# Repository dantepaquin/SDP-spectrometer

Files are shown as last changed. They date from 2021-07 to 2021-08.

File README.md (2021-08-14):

# SDP-Spectrometer

This is the joint repository for the hardware and software for the UCSC EE SDP 2021 Spectrometer. 
The directory *kicad-libraries* contains all of the design files for the hardware, including the schematics, kicad projects, footprint & symbol libraries, and gerbers.
The directory *microcontroller-libraries* contains all of the software used by our spectrometer.

## Kicad Libraries
In our design, we used [KiCad v5.1.0](https://www.kicad.org/blog/2019/03/KiCad-5.1.0-Release/) to create libraries for footprints, symbols, schematics, and pcbs. Currently, the initial designs are in their first revision, and we have fabricated prototypes to be tested.

While our design uses five separate boards connected with wires, all designs are located within a single KiCad project, "main.pro."

### Overview of directories:
#### Adafruit-PowerBoost-1000C-master/
Our design uses an existing power delivery board, and this folder contains the physical design documents that we referenced and used in our own.

#### Backup/
An almost-empty folder used for managing local backups and versioining. Can be removed.

#### RN4678dev/
This contains a kicad project and its design files for a development board, opening the SMD footprint to machine headers. These are not necessary for the final design.

#### Renders/
This contains PDF views of the current PCBs, shown with a small selection of layers.

#### SC70-Dev/
This is a development board used for the SC70 footprint, allowing breadboard verification of our systems. This contains a kicad project with the scematic and PCB files.

#### Separate/
This directory contains subdirectories for each of the five PCBs of our design, which allowed us to manufacture individual boards rather than the full set. This also includes the gerbers used to manufacture the initial run of boards. 

#### Wiring Diagram/
This was a development project to identify and plan the necessary connections between the components of our design. It exists for reference, and has no physical form.

#### spectrometer_core.pretty/
This is the footprint library directory, implementing the physical dimensions and connections of each device used in our design.

#### fp-lib-table
This file tells KiCad how to associate the symbols in our schematic with the footprints in spectrometer_core.pretty.

#### main-cache.lib
This file keeps track of all of the symbols used in the schematic.

#### main.kicad_pcb
This is the main PCB file, which is used to design and lay out the footprints into their physical form.

#### main.pro
**This is the main project file of the spectrometer.** Opening this with kicad will give you access to design and change the footprints, symbols, schematics, and PCBs of the design.

#### main.sch
This is the main schematic file, used to establish connections between the components of the design.

#### spectrometer_core.bck
This is a local backup of the spectrometer_core.dcm file, and can be removed.

#### spectrometer_core.dcm
This keeps track of any documentation we added to the symbol library.

#### spectrometer_core.lib
This is our main symbol library, used to represent the components as used on our schematic.

#### sym-lib-table
This keeps track of the symbol libraries used in the main project.

## Microcontroller Libraries

Our project uses a [TeensyLC](https://www.pjrc.com/teensy/teensyLC.html) running [Arduino](https://www.arduino.cc/en/software), and was developed in the Arduino IDE. This directory contains the code we were able to complete, and verious sketches of test programs.

### Overview of directories:

#### Bluetooth/
This directory contains the currnent state of the bluetooth library implementation. The files include CircularBuffer.c/h, used for UART communication; RN4678.cpp/h, the main library file for the RN4678 bluetooth module; and RN4678_Command.h, a file containing all of the available bluetooth commands.

#### Examples/
This directory includes arduino sketches used to verify both the hardware and minor software usage in our design. These will allow basic back-and-forth, following PC -> USB -> Teesny -> UART -> RN4678 -> Bluetooth -> Phone

#### TeesnyMain/
This is the main directory of code running on the TeensyLC, TeensyMain.ino, and includes state machines and libraries used in our design.  

#### Adafruit_SSD1306.cpp/h
This is an open library by Adafruit designed for our OLED screen, based on the SSD1306 driver IC.

#### FiniteStateMachine.cpp/h
This is an old backup of the driving state machine of our microcontroller. The updated version is in TeensyMain/

#### LED.cpp/h
These files are basic LED drivers for arduino, and can be ignored.

#### RN4678_Command.h
This is a backup of the same file located in Bluetooth/. Both files include usage documentation inside

#### TeensyMain.ino
This is an old backup of the main arduino sketch within TeensyMain/, and can be ignored.

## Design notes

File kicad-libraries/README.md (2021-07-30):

# Repository for KiCad Libraries and design

Individual design files (footprints & symbols) will go into part-specific subfolders in the "Separate" folder

KiCad organization basics:  
.LIB files store SCHEMATIC SYMBOLS  
.PRETTY folders store FOOTPRINT MODELS  
The two should be associated in their current form. 

Further work includes building basic building-block circuits so that integration is easier later on.

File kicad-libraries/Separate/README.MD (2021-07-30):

# Individual EDA files

This folder contains all of the individual projects for each of the boards.

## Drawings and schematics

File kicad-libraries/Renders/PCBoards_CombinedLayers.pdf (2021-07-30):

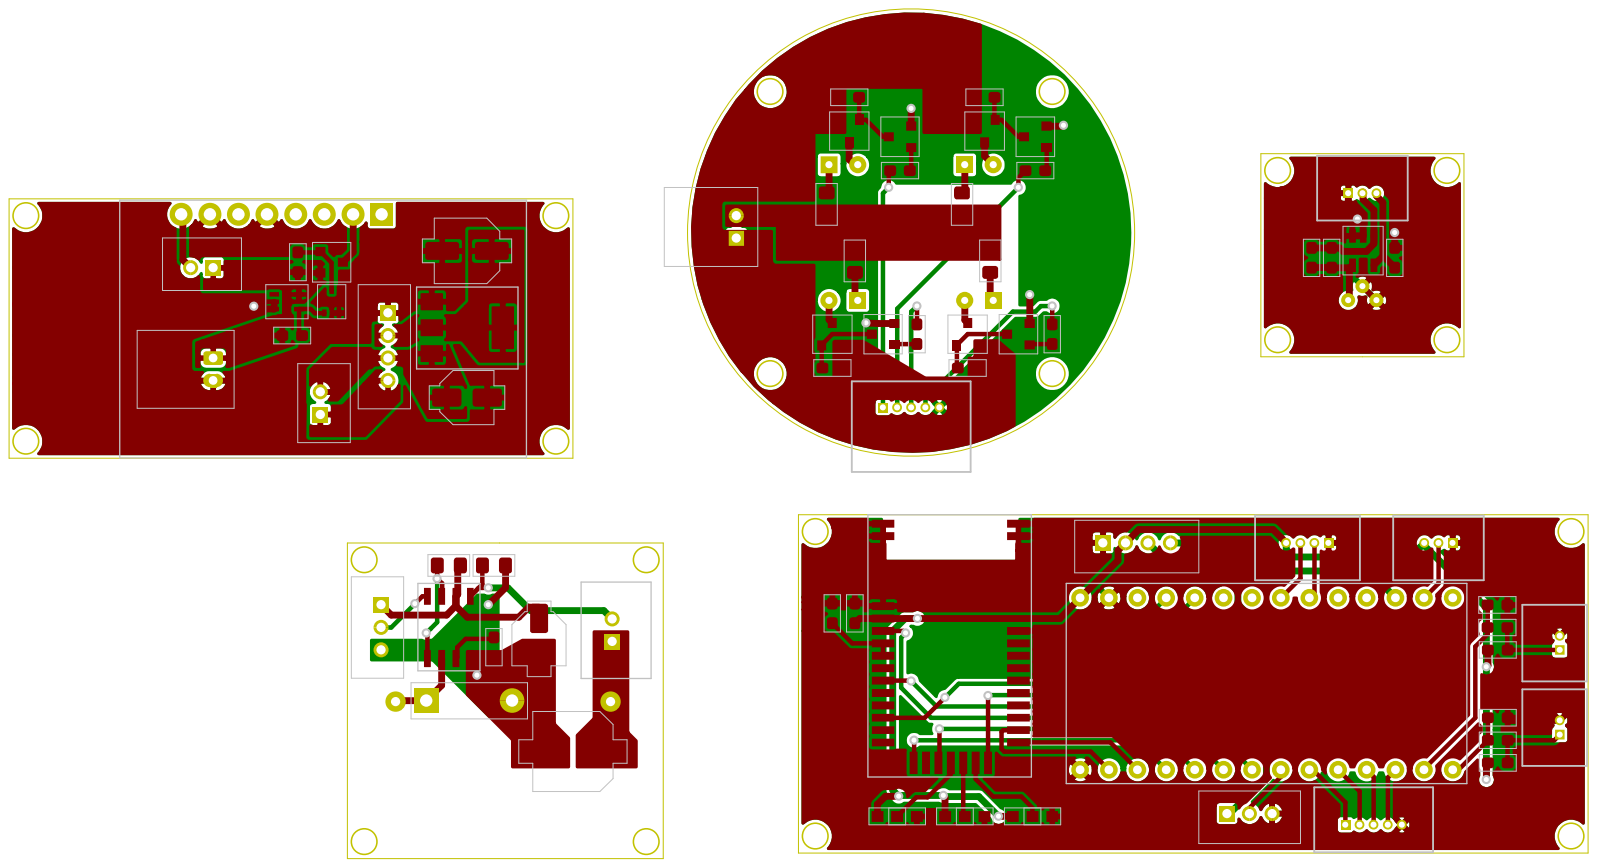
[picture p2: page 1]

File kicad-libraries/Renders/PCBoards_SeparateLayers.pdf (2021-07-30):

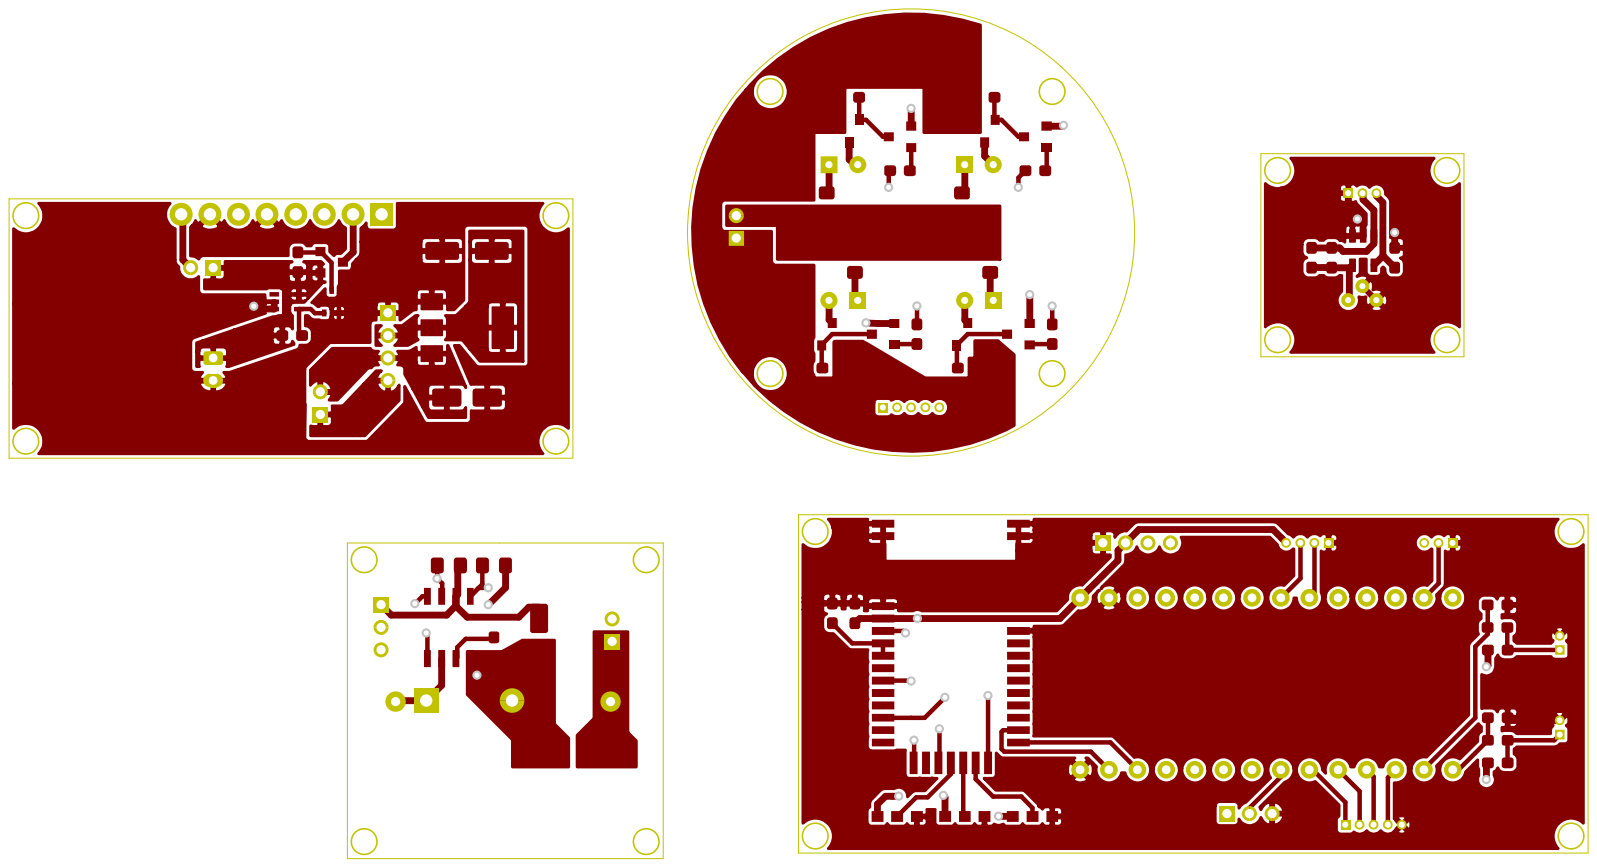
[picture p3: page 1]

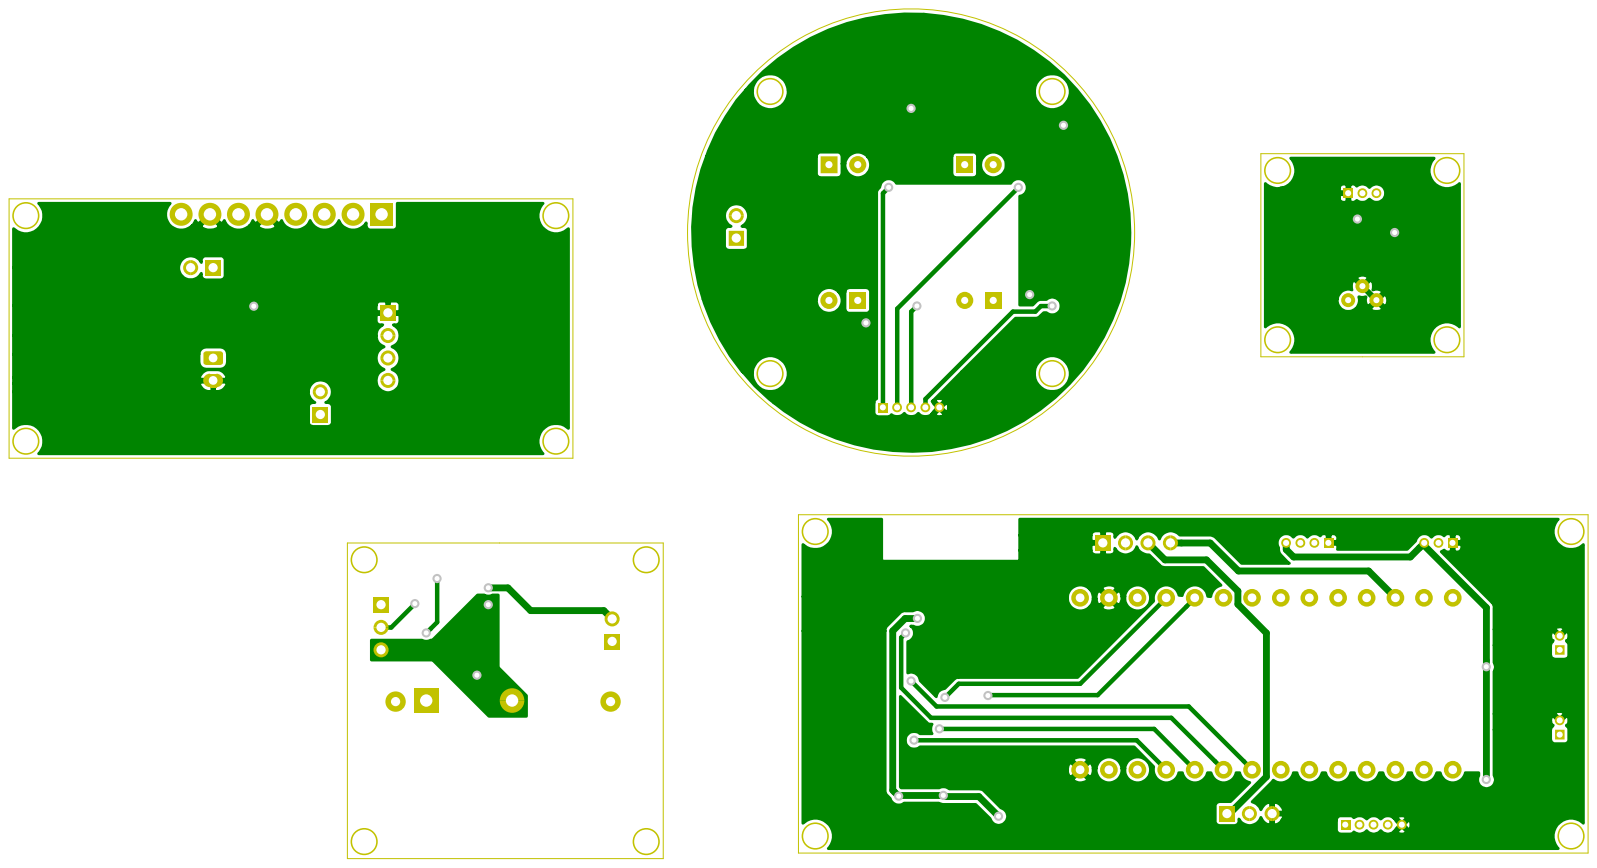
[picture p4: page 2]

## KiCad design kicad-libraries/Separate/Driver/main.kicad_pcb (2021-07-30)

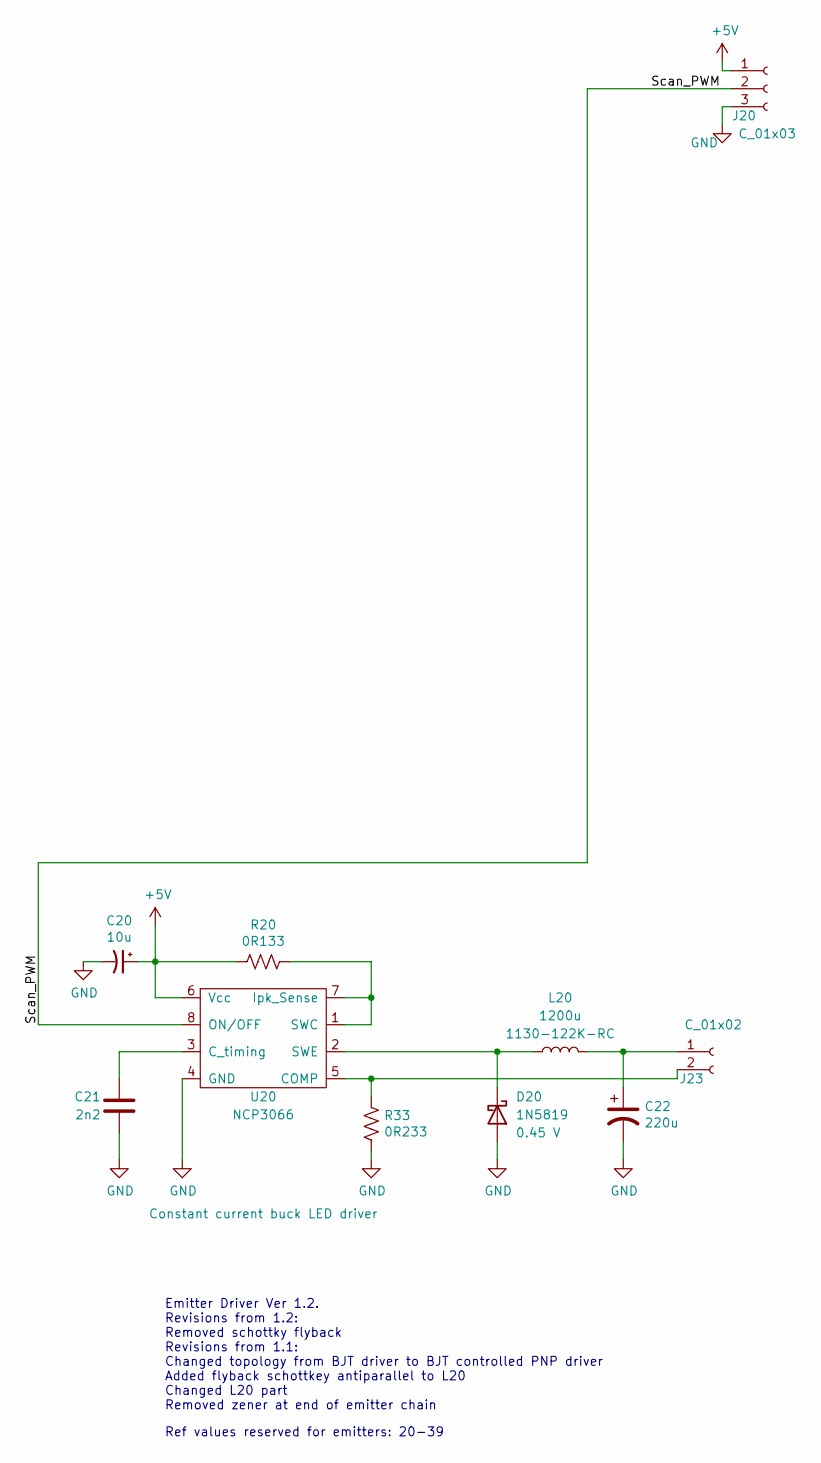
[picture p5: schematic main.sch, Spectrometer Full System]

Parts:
C20: 10u; CP_Elec_4x3
C21: 2n2; C_0603_1608Metric_Pad1.05x0.95mm_HandSolder
C22: 220u; CP_Elec_6.3x5.9
D20: 1N5819; D_DO-41_SOD81_P7.62mm_Horizontal
J20: C_01x03; 1x03_Vert_P2.00_Molex_Micro-Latch
J23: C_01x02; 1x02_Vert_P2.00_Molex_Micro-Latch
L20: 1200u; 1130-122K-RC
R20: 0R133; R_0805_2012Metric_Pad1.15x1.40mm_HandSolder
R33: 0R233; R_0805_2012Metric_Pad1.15x1.40mm_HandSolder
U20: NCP3066; SOIC-8

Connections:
+5V: C20.1, J20.1, R20.1, U20.6 (Vcc)
/Scan_PWM: J20.2, U20.8 (ON/OFF)
GND: C20.2, C21.2, C22.2, D20.2 (A), J20.3, R33.2, U20.4 (GND)
unnamed: C21.1, U20.3 (C_timing)
unnamed: C22.1, J23.1, L20.2
unnamed: D20.1 (K), L20.1, U20.2 (SWE)
unnamed: J23.2, R33.1, U20.5 (COMP)
unnamed: R20.2, U20.1 (SWC), U20.7 (Ipk_Sense)

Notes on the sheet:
Emitter Driver Ver 1.2. Revisions from 1.2: Removed schottky flyback Revisions from 1.1: Changed topology from BJT driver to BJT controlled PNP driver Added flyback schottkey antiparallel to L20 Changed L20 part Removed zener at end of emitter chain
Ref values reserved for emitters: 20-39

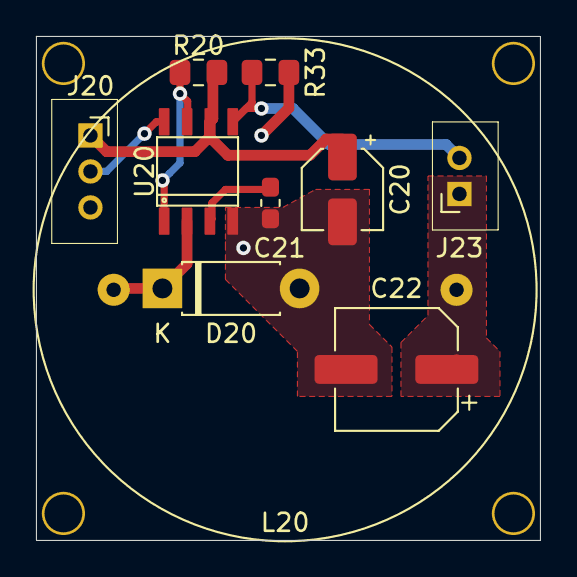
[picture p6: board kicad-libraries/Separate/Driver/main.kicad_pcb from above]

Board: 2 copper layers, 28.0 x 28.0 mm, 10 parts (0 on the bottom side), 8 nets.

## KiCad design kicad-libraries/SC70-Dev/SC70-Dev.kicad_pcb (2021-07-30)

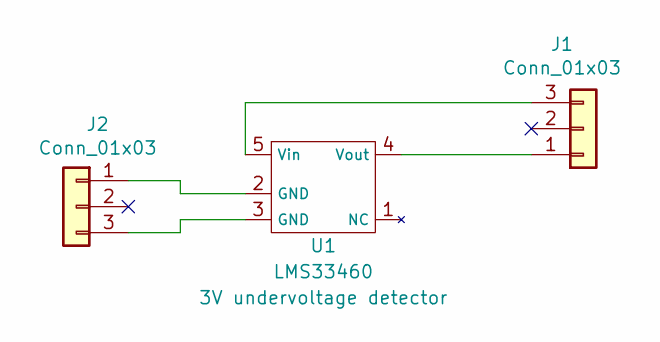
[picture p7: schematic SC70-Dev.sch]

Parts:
J1, J2: Conn_01x03; PinHeader_1x03_P2.54mm_Vertical
U1: LMS33460; SC70

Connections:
unnamed: J1.1, U1.4 (Vout)
unnamed: J1.3, U1.5 (Vin)
unnamed: J2.1, U1.2 (GND)
unnamed: J2.3, U1.3 (GND)

Board: 2 copper layers, 3 parts (0 on the bottom side), 4 nets, no tracks yet.

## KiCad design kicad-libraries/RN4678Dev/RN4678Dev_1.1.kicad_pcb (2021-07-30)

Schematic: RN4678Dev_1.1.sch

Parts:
C1, C2: C; C_0603_1608Metric
D1: LED; LED_0603_1608Metric
J1, J2: Conn_01x11_Male; PinHeader_1x11_P2.54mm_Vertical
JP1, JP2, JP3: J3; PinHeader_1x03_P2.54mm_Vertical
M1: RN4678
R1: R; R_0603_1608Metric

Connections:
+BATT: C1.1, J1.1, JP1.3, JP2.3, JP3.3, M1.4 (BAT_IN)
/04: J1.5, M1.11 (P0_4)
/05: J1.9, M1.16 (P0_5)
/12: J1.7, M1.13 (P1_2)
/13: J1.8, M1.14 (P1_3)
/15: J1.6, M1.12 (P1_5)
/31: J2.5, M1.24 (P3_1)
/32: J2.6, M1.25 (P3_2)
/33: J2.7, M1.26 (P3_3)
/34: J2.8, M1.27 (P3_4)
/36: J2.9, M1.28 (P3_6)
/37: J2.10, M1.29 (P3_7)
/CTS: J2.1, M1.15 (P1_7/CTS)
/LDO33: C2.1, M1.6 (LDO33_O), M1.7 (VDD_IO), R1.2
/RST_N: J1.10, M1.21 (RST_N)
/RTS: J2.2, M1.17 (P0_0/RTS)
/RXD: J2.3, M1.22 (RXD)
/SWBTN: J1.3, M1.5 (SW_BTN)
/TXD: J2.4, M1.23 (TXD)
/WAKEUP: J1.4, M1.9 (WAKEUP)
GND: C1.2, C2.2, J1.2, J1.11, J2.11, JP1.1, JP2.1, JP3.1, M1.1 (GND), M1.2 (GND), M1.3 (GND), M1.31 (GND), M1.32 (GND), M1.33 (GND)
unnamed 21: D1.1 (K), M1.30 (LED); also elsewhere on the board
unnamed 22: R1.1; also elsewhere on the board
unnamed: JP1.2, M1.18 (P2_0)
unnamed: JP2.2, M1.19 (P2_4)
unnamed: JP3.2, M1.20 (EAN)

Board: 2 copper layers, 10 parts (3 on the bottom side), 26 nets, no tracks yet.

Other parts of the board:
>|: LED; LED_0603_1608Metric

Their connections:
unnamed 21: >|.1; also elsewhere on the board
unnamed 22: >|.2; also elsewhere on the board

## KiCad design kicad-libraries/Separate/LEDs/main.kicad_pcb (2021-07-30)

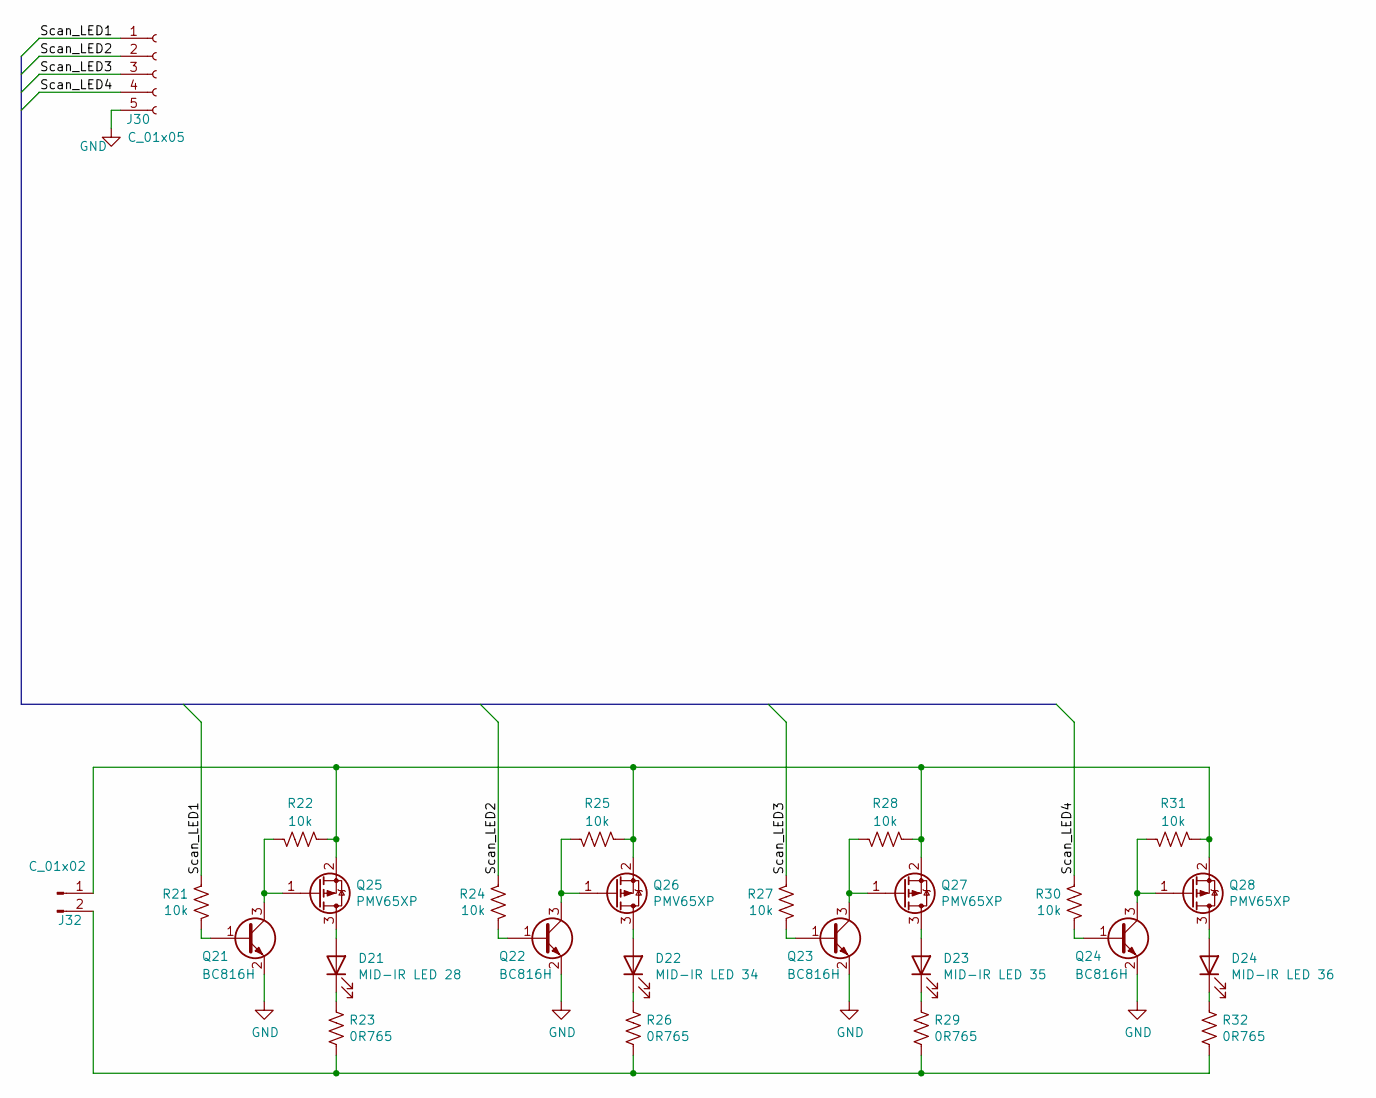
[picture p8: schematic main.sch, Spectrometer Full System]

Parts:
D21: MID-IR LED 28; TO-18R
D22: MID-IR LED 34; TO-18R
D23: MID-IR LED 35; TO-18R
D24: MID-IR LED 36; TO-18R
J30: C_01x05; 530480550
J32: C_01x02; 1x02_Horiz_P2.00_Molex_Micro-Latch
Q21, Q22, Q23, Q24: BC816H; SOT-23
Q25, Q26, Q27, Q28: PMV65XP; SOT-23
R21, R22, R24, R25, R27, R28, R30, R31: 10k; R_0603_1608Metric_Pad1.05x0.95mm_HandSolder
R23, R26, R29, R32: 0R765; R_0805_2012Metric_Pad1.15x1.40mm_HandSolder

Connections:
/Scan_LED1: J30.1, R21.1
/Scan_LED2: J30.2, R24.1
/Scan_LED3: J30.3, R27.1
/Scan_LED4: J30.4, R30.1
GND: J30.5, Q21.2 (E), Q22.2 (E), Q23.2 (E), Q24.2 (E)
unnamed: D21.1 (K), R23.1
unnamed: D21.2 (A), Q25.3 (D)
unnamed: D22.1 (K), R26.1
unnamed: D22.2 (A), Q26.3 (D)
unnamed: D23.1 (K), R29.1
unnamed: D23.2 (A), Q27.3 (D)
unnamed: D24.1 (K), R32.1
unnamed: D24.2 (A), Q28.3 (D)
unnamed: J32.1, Q25.2 (S), Q26.2 (S), Q27.2 (S), Q28.2 (S), R22.1, R25.1, R28.1, R31.1
unnamed: J32.2, R23.2, R26.2, R29.2, R32.2
unnamed: Q21.1 (B), R21.2
unnamed: Q21.3 (C), Q25.1 (G), R22.2
unnamed: Q22.1 (B), R24.2
unnamed: Q22.3 (C), Q26.1 (G), R25.2
unnamed: Q23.1 (B), R27.2
unnamed: Q23.3 (C), Q27.1 (G), R28.2
unnamed: Q24.1 (B), R30.2
unnamed: Q24.3 (C), Q28.1 (G), R31.2

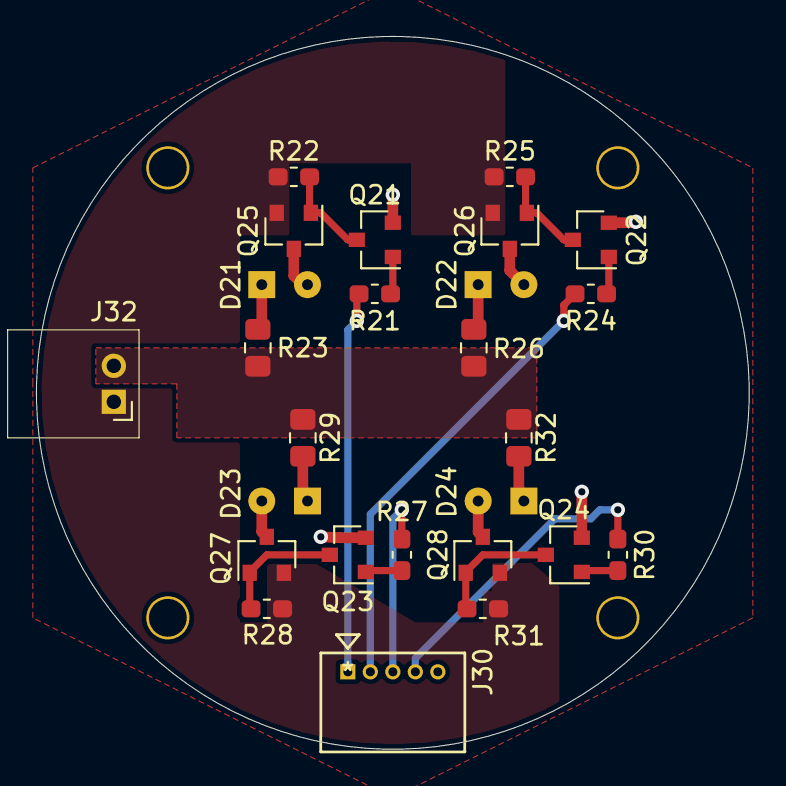
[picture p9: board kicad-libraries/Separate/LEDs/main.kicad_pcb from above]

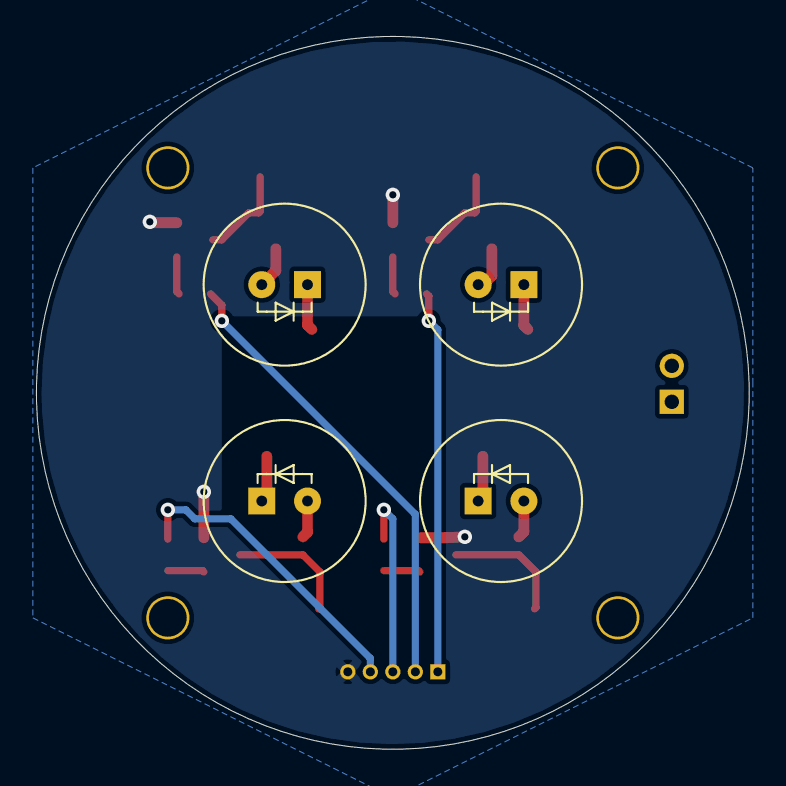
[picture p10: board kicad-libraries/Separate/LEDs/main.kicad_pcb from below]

Board: 2 copper layers, 39.6 x 39.6 mm, 26 parts (4 on the bottom side), 23 nets.

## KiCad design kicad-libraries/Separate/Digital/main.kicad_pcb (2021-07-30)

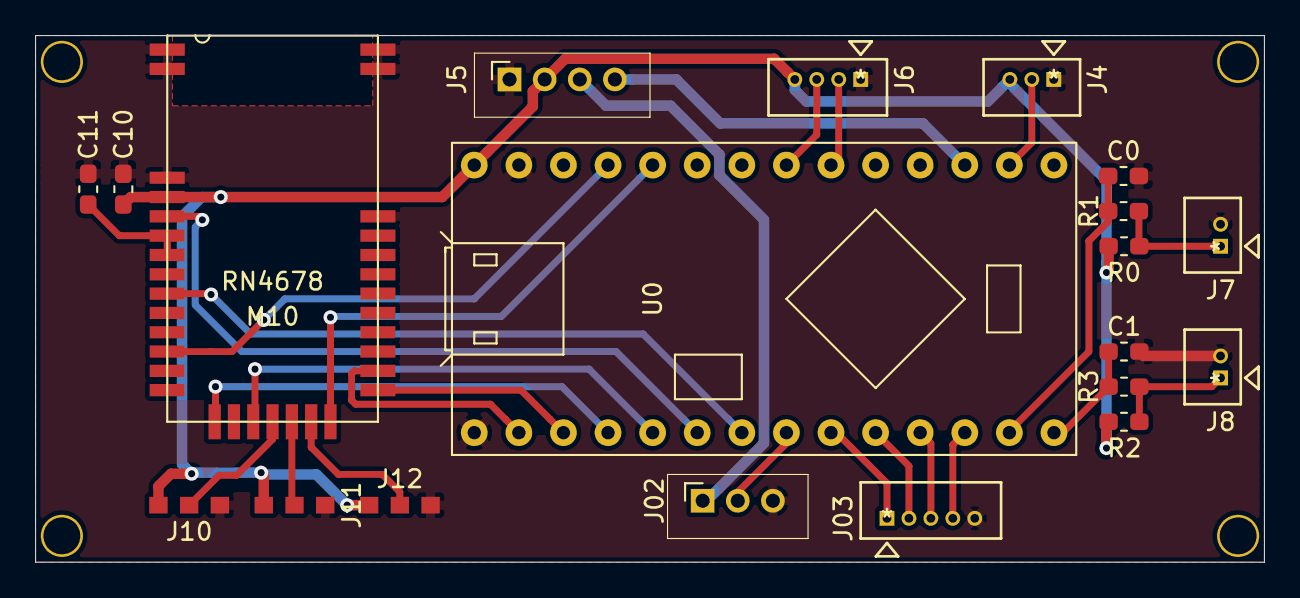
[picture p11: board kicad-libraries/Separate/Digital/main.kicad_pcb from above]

Board: 2 copper layers, 70.0 x 30.0 mm, 20 parts (0 on the bottom side), 28 nets.

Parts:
C0, C1: 0.1u; C_0603_1608Metric_Pad1.05x0.95mm_HandSolder
C10: 10u; C_0603_1608Metric_Pad1.05x0.95mm_HandSolder
C11: 1u; C_0603_1608Metric_Pad1.05x0.95mm_HandSolder
J02: C_01x03; 1x03_Vert_P2.00_Molex_Micro-Latch
J03: C_01x05; 530470510
J4: C_01x03; 530470310
J5: C_01x04; 1x04_Vert_P2.00_Molex_Micro-Latch
J6: C_01x04; 530470410
J7, J8: C_01x02; 530470210
J10, J11, J12: Jmp3; Jumper3_0603
M10: RN4678
R0, R2: 100k; R_0603_1608Metric_Pad1.05x0.95mm_HandSolder
R1, R3: 1k; R_0603_1608Metric_Pad1.05x0.95mm_HandSolder
U0: TeensyLC_Inline

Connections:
+3V3: C10.1, J4.3, J5.2, J6.4, J10.1, J11.1, J12.1, M10.4, R0.1, R2.1, U0.VIN
+5V: J02.1, J5.3
+BATT: J5.4, U0.15
/BT_CTS: M10.15, U0.2
/BT_Power: M10.5, U0.4
/BT_RTS: M10.17, U0.3
/BT_Reset: M10.21, U0.22
/BT_Rx: M10.22, U0.1
/BT_Status: M10.12, U0.23
/BT_Tx: M10.23, U0.0
/BT_Wake: M10.9, U0.5
GND: C0.2, C1.2, C10.2, C11.1, J02.3, J03.5, J4.1, J5.1, J6.1, J7.2, J8.2, J10.2, J11.2, J12.2, M10.1, M10.2, M10.3, M10.31, M10.32, M10.33, U0.GND_1, U0.GND_3
unnamed: C0.1, R1.1, U0.11
unnamed: C1.1, R3.1, U0.12
unnamed: C11.2, M10.6, M10.7
unnamed: J02.2, U0.6
unnamed: J03.1, U0.7
unnamed: J03.2, U0.8
unnamed: J03.3, U0.9
unnamed: J03.4, U0.10
unnamed: J4.2, U0.14
unnamed: J6.2, U0.18
unnamed: J6.3, U0.19
unnamed: J7.1, R0.2, R1.2
unnamed: J8.1, R2.2, R3.2
unnamed: J10.3, M10.18
unnamed: J11.3, M10.19
unnamed: J12.3, M10.20

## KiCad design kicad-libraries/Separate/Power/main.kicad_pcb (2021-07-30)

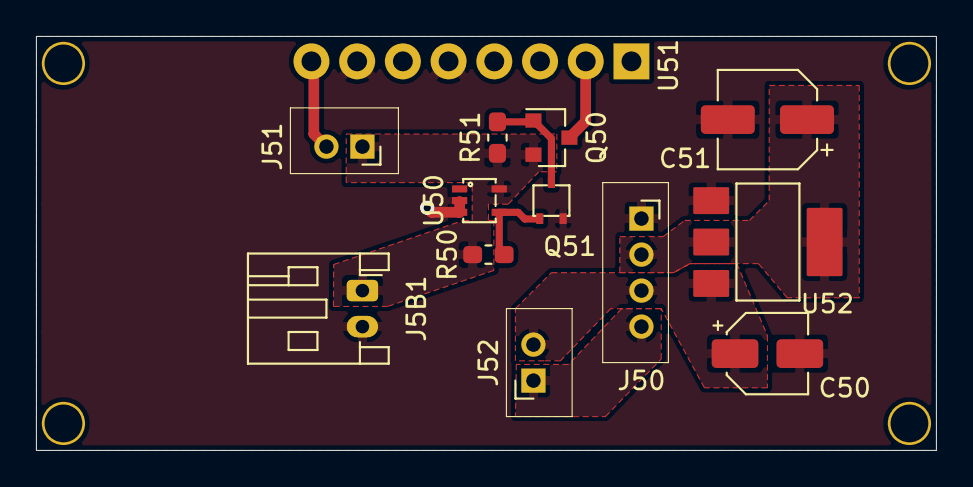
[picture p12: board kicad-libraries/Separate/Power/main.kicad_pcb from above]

Board: 2 copper layers, 50.0 x 23.0 mm, 13 parts (0 on the bottom side), 9 nets.

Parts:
C50: 10u; CP_Elec_4x3
C51: 100u; CP_Elec_5x4.5
J5B1: C_01x02; JST_PH_S2B-PH-K_1x02_P2.00mm_Horizontal
J50: C_01x04; 1x04_Vert_P2.00_Molex_Micro-Latch
J51, J52: C_01x02; 1x02_Vert_P2.00_Molex_Micro-Latch
Q50: SSM3J372R; SOT-23
Q51: SSM3K127TU; UFM-3
R50: 470k; R_0603_1608Metric_Pad1.05x0.95mm_HandSolder
R51: 100k; R_0603_1608Metric_Pad1.05x0.95mm_HandSolder
U50: LMS33460; SC70
U51: PowerBoost1000C; Powerboost1000C
U52: LM1117; SOT-223

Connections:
GND: C50.2, C51.2, J5B1.2, J50.1, Q51.2, U50.2, U50.3, U51.5, U51.7, U52.1
unnamed: C50.1, J50.3, J52.2, U52.3
unnamed: C51.1, J50.2, U52.2
unnamed: J50.4, J52.1
unnamed: J5B1.1, J51.1, Q50.2, R50.1, R51.1, U50.5
unnamed: J51.2, U51.8
unnamed: Q50.1, Q51.3, R51.2
unnamed: Q50.3, U51.2
unnamed: Q51.1, R50.2, U50.4

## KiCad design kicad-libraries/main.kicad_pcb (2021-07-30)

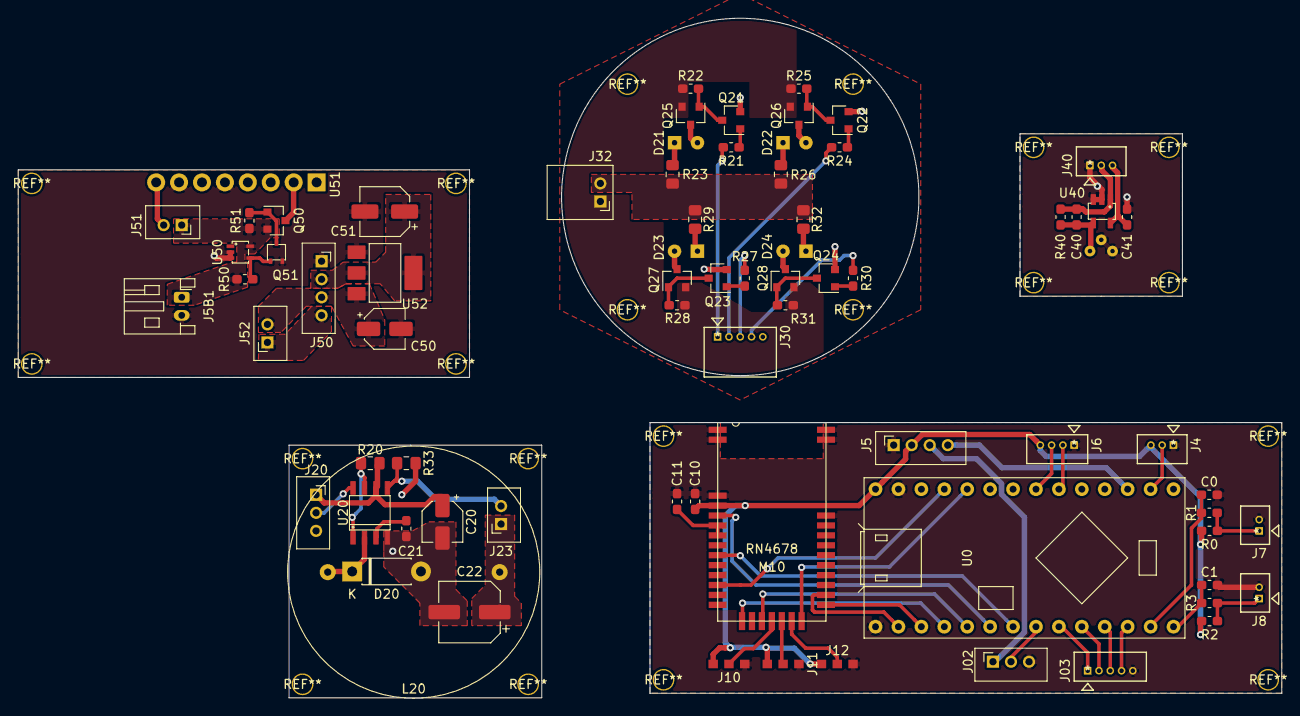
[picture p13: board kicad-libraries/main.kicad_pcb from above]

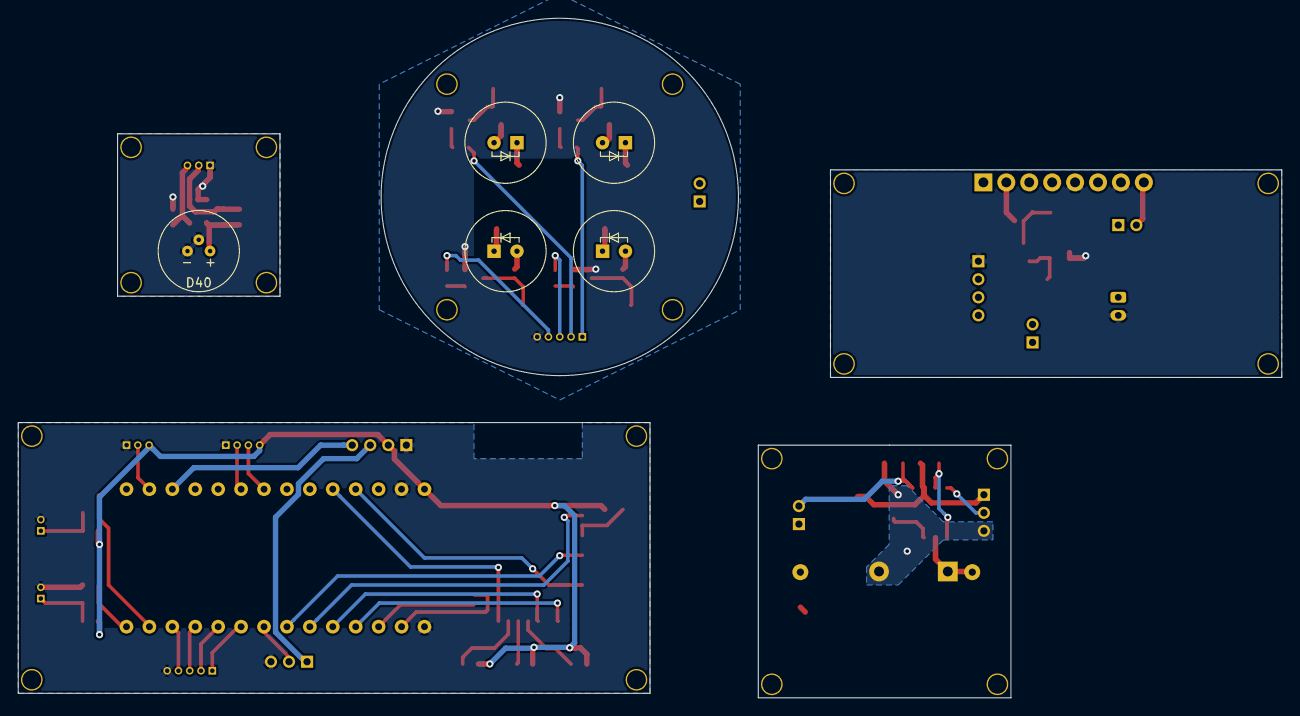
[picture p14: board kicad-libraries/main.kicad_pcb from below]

Board: 2 copper layers, 140.0 x 75.3 mm, 75 parts (5 on the bottom side), 66 nets.

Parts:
C0, C1, C41: 0.1u; C_0603_1608Metric_Pad1.05x0.95mm_HandSolder
C10: 10u; C_0603_1608Metric_Pad1.05x0.95mm_HandSolder
C11: 1u; C_0603_1608Metric_Pad1.05x0.95mm_HandSolder
C20, C50: 10u; CP_Elec_4x3
C21: 2n2; C_0603_1608Metric_Pad1.05x0.95mm_HandSolder
C22: 220u; CP_Elec_6.3x5.9
C40: 27n; C_0603_1608Metric_Pad1.05x0.95mm_HandSolder
C51: 100u; CP_Elec_5x4.5
D20: 1N5819; D_DO-41_SOD81_P7.62mm_Horizontal
D21: MID-IR LED 28; TO-18R
D22: MID-IR LED 34; TO-18R
D23: MID-IR LED 35; TO-18R
D24: MID-IR LED 36; TO-18R
D40: PD41-03; TO-18_WithReflector
J02, J20: C_01x03; 1x03_Vert_P2.00_Molex_Micro-Latch
J03: C_01x05; 530470510
J4, J40: C_01x03; 530470310
J5, J50: C_01x04; 1x04_Vert_P2.00_Molex_Micro-Latch
J5B1: C_01x02; JST_PH_S2B-PH-K_1x02_P2.00mm_Horizontal
J6: C_01x04; 530470410
J7, J8: C_01x02; 530470210
J10, J11, J12: Jmp3; Jumper3_0603
J23, J51, J52: C_01x02; 1x02_Vert_P2.00_Molex_Micro-Latch
J30: C_01x05; 530480550
J32: C_01x02; 1x02_Horiz_P2.00_Molex_Micro-Latch
L20: 1200u; 1130-122K-RC
M10: RN4678
Q21, Q22, Q23, Q24: BC816H; SOT-23
Q25, Q26, Q27, Q28: PMV65XP; SOT-23
Q50: SSM3J372R; SOT-23
Q51: SSM3K127TU; UFM-3
R0, R2, R51: 100k; R_0603_1608Metric_Pad1.05x0.95mm_HandSolder
R1, R3: 1k; R_0603_1608Metric_Pad1.05x0.95mm_HandSolder
R20: 0R133; R_0805_2012Metric_Pad1.15x1.40mm_HandSolder
R21, R22, R24, R25, R27, R28, R30, R31: 10k; R_0603_1608Metric_Pad1.05x0.95mm_HandSolder
R23, R26, R29, R32: 0R765; R_0805_2012Metric_Pad1.15x1.40mm_HandSolder
R33: 0R233; R_0805_2012Metric_Pad1.15x1.40mm_HandSolder
R40: 10k1; R_0603_1608Metric_Pad1.05x0.95mm_HandSolder
R50: 470k; R_0603_1608Metric_Pad1.05x0.95mm_HandSolder
U0: TeensyLC_Inline
U20: NCP3066; SOIC-8
U40: OPA990; SOT-23-5
U50: LMS33460; SC70
U51: PowerBoost1000C; Powerboost1000C
U52: LM1117; SOT-223

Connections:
+3V3: C10.1, C41.1, J4.3, J5.2, J6.4, J10.1, J11.1, J12.1, J40.3, M10.4, R0.1, R2.1, U0.VIN, U40.5
+5V: C20.1, J02.1, J5.3, J20.1, R20.1, U20.6
+BATT: J5.4, U0.15
/BT_CTS: M10.15, U0.2
/BT_Power: M10.5, U0.4
/BT_RTS: M10.17, U0.3
/BT_Reset: M10.21, U0.22
/BT_Rx: M10.22, U0.1
/BT_Status: M10.12, U0.23
/BT_Tx: M10.23, U0.0
/BT_Wake: M10.9, U0.5
/Scan_LED1: J30.1, R21.1
/Scan_LED2: J30.2, R24.1
/Scan_LED3: J30.3, R27.1
/Scan_LED4: J30.4, R30.1
/Scan_PWM: J20.2, U20.8
GND: C0.2, C1.2, C10.2, C11.1, C20.2, C21.2, C22.2, C41.2, C50.2, C51.2, D20.2, D40.1, D40.3, J02.3, J03.5, J4.1, J5.1, J5B1.2, J6.1, J7.2, J8.2, J10.2, J11.2, J12.2, J20.3, J30.5, J40.1, J50.1, M10.1, M10.2, M10.3, M10.31, M10.32, M10.33, Q21.2, Q22.2, Q23.2, Q24.2, Q51.2, R33.2, U0.GND_1, U0.GND_3, U20.4, U40.2, U40.3, U50.2, U50.3, U51.5, U51.7, U52.1
unnamed: C0.1, R1.1, U0.11
unnamed: C1.1, R3.1, U0.12
unnamed: C11.2, M10.6, M10.7
unnamed: C21.1, U20.3
unnamed: C22.1, J23.1, L20.2
unnamed: C40.1, J40.2, R40.2, U40.1
unnamed: C40.2, D40.2, R40.1, U40.4
unnamed: C50.1, J50.3, J52.2, U52.3
unnamed: C51.1, J50.2, U52.2
unnamed: D20.1, L20.1, U20.2
unnamed: D21.1, R23.1
unnamed: D21.2, Q25.3
unnamed: D22.1, R26.1
unnamed: D22.2, Q26.3
unnamed: D23.1, R29.1
unnamed: D23.2, Q27.3
unnamed: D24.1, R32.1
unnamed: D24.2, Q28.3
unnamed: J02.2, U0.6
unnamed: J03.1, U0.7
unnamed: J03.2, U0.8
unnamed: J03.3, U0.9
unnamed: J03.4, U0.10
unnamed: J4.2, U0.14
unnamed: J6.2, U0.18
unnamed: J6.3, U0.19
unnamed: J7.1, R0.2, R1.2
unnamed: J8.1, R2.2, R3.2
unnamed: J10.3, M10.18
unnamed: J11.3, M10.19
unnamed: J12.3, M10.20
unnamed: J23.2, R33.1, U20.5
unnamed: J32.1, Q25.2, Q26.2, Q27.2, Q28.2, R22.1, R25.1, R28.1, R31.1
unnamed: J32.2, R23.2, R26.2, R29.2, R32.2
unnamed: J50.4, J52.1
unnamed: J5B1.1, J51.1, Q50.2, R50.1, R51.1, U50.5
unnamed: J51.2, U51.8
unnamed: Q21.1, R21.2
unnamed: Q21.3, Q25.1, R22.2
unnamed: Q22.1, R24.2
unnamed: Q22.3, Q26.1, R25.2
unnamed: Q23.1, R27.2
unnamed: Q23.3, Q27.1, R28.2
unnamed: Q24.1, R30.2
unnamed: Q24.3, Q28.1, R31.2
unnamed: Q50.1, Q51.3, R51.2
unnamed: Q50.3, U51.2
unnamed: Q51.1, R50.2, U50.4
unnamed: R20.2, U20.1, U20.7

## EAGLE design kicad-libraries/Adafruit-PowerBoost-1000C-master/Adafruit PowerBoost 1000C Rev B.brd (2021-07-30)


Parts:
B1: JST 2-PH; JSTPH2
C1, C7, C8: 10uF; 0805-NO
C2: 2.2uF; 0805-NO
C4: 0.1uF; 0805_10MGAP
C6: 100uF; C1210
CHRG/LBO: ORANGE; CHIPLED_0805_NOOUTLINE
CN1: USBA_FEMALE; USB_HOST-PTH
CN4: MicroUSB; 4UCONN_20329
DONE: GREEN; CHIPLED_0805_NOOUTLINE
FID1, FID2, FID3: FIDUCIAL""; FIDUCIAL_1MM
JP2: HEADER-1X8ROUND; 1X08_ROUND
L1: 6.8uH; INDUCTOR_5X5MM_TDK_VLC5045
LED1: RED; CHIPLED_0805_NOOUTLINE
LED2: BLUE; CHIPLED_0805_NOOUTLINE
R1: 1.87M; _0805MP
R2: 340K; _0805MP
R3: 1.87M; 0805-NO
R4, R13: 200K; 0805-NO
R5, R8, R14, R20: 1K; 0805-NO
R6: 270K; 0805-NO
R7, R17: 100K; 0805-NO
R9: 43K; 0805-NO
R10: 49.9K; 0805-NO
R11: 75K 1%; 0805-NO
R12: 49.9K 1%; 0805-NO
R16: 1.0K; 0805-NO
T1: MMUN2133LT1G; SC59-BEC
THERM: 15K; 0805-NO
U1: TPS61090RSAR; PVQFN-16
U2: MCP73871; QFN20_4MM
U$10, U$11: MOUNTINGHOLE2.5; MOUNTINGHOLE_2.5_PLATED
X1: TERMBLOCK_1X2; TERMBLOCK_1X2-3.5MM

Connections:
5.0V: C2.1, C6.1, CN1.VBUS, JP2.8, R3.2, R5.1, R9.2, R11.2, U1.1 (VOUT), U1.15 (VOUT), U1.16 (VOUT), X1.2
D+: CN1.D+, R11.1, R12.1
D-: CN1.D-, R9.1, R10.1
ENABLE: JP2.4, R13.2, U1.11 (EN)
GND: B1.1 (-), C1.2, C2.2, C4.2, C6.2, C7.2, C8.2, CN1.GND, CN4.BASE@1 (GND), CN4.BASE@2 (GND), CN4.GND, CN4.SPRT@1 (GND), CN4.SPRT@2 (GND), CN4.SPRT@3 (GND), CN4.SPRT@4 (GND), JP2.5, JP2.7, LED1.C, LED2.C, R2.1, R4.1, R7.2, R10.2, R12.2, R16.1, R17.1, THERM.1, U1.5 (PGND), U1.6 (PGND), U1.7 (PGND), U1.10 (SYNC), U1.13 (GND), U1.P$18 (PGND), U1.P$19 (PGND), U1.P$20 (PGND), U1.P$21 (PGND), U1.P$22 (PGND), U1.THERMAL (PGND), U2.P$10 (VSS1), U2.P$11 (VSS2), U2.P$21 (THERMAL), X1.1
LBO: JP2.6, T1.B, U1.12 (LBO)
unnamed: L1.P$2 (2), U1.3 (SW), U1.4 (SW)
unnamed: LED1.A, R20.1
unnamed: R1.1, R2.2, U1.9 (LBI)
unnamed: LED2.A, R5.2
unnamed: R3.1, R4.2, U1.14 (FB)
unnamed: R20.2, T1.C
unnamed: R6.1, R7.1, U2.P$2 (VPCC)
unnamed: DONE.C, R14.2
unnamed: R14.1, U2.P$7 (STAT2)
unnamed: THERM.2, U2.P$5 (THERM)
unnamed: R8.1, U2.P$8 (STAT1/LBO)
unnamed: CHRG/LBO.C, R8.2
unnamed: R17.2, U2.P$12 (PROG3)
unnamed: R16.2, U2.P$13 (PROG1)
VBAT: C1.1, C4.1, JP2.3, L1.P$1 (1), R1.2, R13.1, T1.E, U1.8 (VBAT), U2.P$1 (VOUT1), U2.P$20 (VOUT2)
VBUS: C8.1, CHRG/LBO.A, CN4.VBUS, DONE.A, JP2.1, R6.2, U2.P$3 (SEL), U2.P$4 (PROG2), U2.P$9 (/TE), U2.P$17 (CE), U2.P$18 (VIN1), U2.P$19 (VIN2)
VLIPO: B1.2 (+), C7.1, JP2.2, U2.P$14 (VBAT1), U2.P$15 (VBAT2), U2.P$16 (VBATSENS)

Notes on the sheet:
Both grounds must be connected on the PCB at only one point close to the GND pin.
On/Off Switch
See Pg 15 1st para
6.8uH power w/2A current
R3 = 1.9Mohm for 5.2V R3 = 1.1Mohm for 3.3V
Charge Rate = 1000V/PROG1
1.0K = 1000mA
2.0K = 500mA
No Thermistor:
10K NTC Thermistor:
RT1 = 0, RT2 = 10K
RT1 = TBD, RT2 = TBD



Board: 2 copper layers, 36.1 x 22.9 mm, 47 parts (2 on the bottom side), 23 nets.

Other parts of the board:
U$12: PCBFEAT-REV-040
U$25: SYMBOL_PLUS
U$26: SYMBOL_MINUS
U$28: ADAFRUIT_5MM
U$45: ADAFRUIT_3.5MM

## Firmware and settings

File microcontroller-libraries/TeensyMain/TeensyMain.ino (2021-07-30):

/*
 * TeensyMain
 * 
 * Chris Massiello
 * Last Update: 5/6/2021
 * 
 * Description: This program controls the state of a portable, PLA spectrometer by using a finite
 * state machine. This controls when the spectrometer performs a scan, when the spectrometer tries
 * to connect to a mobile app via bluetooth, and when it goes into power saving mode.
 * 
 */

/*libraries*/
#include <Adafruit_GFX.h>
#include <Adafruit_SSD1306.h>

//
#include "FiniteStateMachine.h"
/*
#define CPU_PRESCALE(n) (CLKPR = 0x80, CLKPR = (n))//defining macro to change cpu clock speed
#define CPU_8MHz        0x01 //values over 8 MHz can be used but would cause the teensy LC to overclock, hence * MHz will be max value that we want to use
#define CPU_4MHz        0x02 //putting these here in case we want to change the cpu clock speed
#define CPU_2MHz        0x03
#define CPU_1MHz        0x04

CPU_PRESCALE(CPU_8MHz);*/


/*creates list of State object that are a part of FSM class
  State STATE = State(method)
  being in the state, STATE, will cause the method passed in State(method) to execute*/
State IDLE_STATE = State(idle);
State POWER_SAVING = State(Power_saving);
State SCANNING = State(scanning);
State BL_SEARCHING = State(BL_search);
State TRANSMITTING = State(data_trans);


/*FSM SPEC = FSM(START), creates finite state machine class that starts in the state named START
  Creates FiniteStateMachine class that will start in the IDLE state*/
FSM SPEC = FSM(IDLE_STATE); 

//defining constants for pins

//UART pins
#define RX 0
#define TX 1
#define CTS 2
#define RTS 3

//pushbuttons
#define SW1 11 // Pin 11 for SW1, aka pushbutton to start bluetooth pairing
#define SW2 12 // Pin 12 for SW2, aka pushbutton to start plastic scan

//analog pins
#define A0 15 // Pin 15 for monitoring battery level
#define DET 14// Pin 14 for reading from detector

//digital pins controlling the LEDs
#define LED1 7 // Pin 7 for LED1
#define LED2 8 // Pin 8 for LED2
#define LED3 9 // Pin 9 for LED3
#define LED4 10 // Pin 10 for LED4
#define LED_pulse 6 // Pin 6 for controlling the BJTs that allow each LED to get current 

// digital pin for resetting the OLED display
#define OLED_RESET 4 // defines the reset pin for the OLED display
Adafruit_SSD1306 display( OLED_RESET); //creates instance of Adafruit_SSD1306 with reset pin OLED_RESET

// global constants
float timer_start = 0;

// timer_count is the counter value that is incremented whenever the timer interrupt overflows 
// needs to be volatile because it is passed into an interrupt
volatile uint8_t timer_count = 0;

void setup() {

  Serial.begin(115200); // setting baudrate for 115200 bits/s, 115200 is baudrate for RN4678

  //display defaults to using SDA0 and SCL0 which is pin 18 and 19
  // 0x3C is the screen address, currently 128x32 pixels. 0x3D is 128x64 pixels but am having trouble running that
  // SSD1306_SWITCHCAPVCC = generate display voltage from 3.3V internally
  display.begin(SSD1306_SWITCHCAPVCC, 0x3C);//sets display as 128x32 format

  display.setTextSize(1);
  display.setTextColor(WHITE);

  display.clearDisplay();

  // Enable entry into VLPR, LLS or VLLS modes.
  SMC_PMPROT |= SMC_PMPROT_AVLP | SMC_PMPROT_ALLS | SMC_PMPROT_AVLLS;
  
  pinMode(SW1, INPUT);
  pinMode(SW2, INPUT);

  pinMode(LED1, OUTPUT);
  pinMode(LED2, OUTPUT);
  pinMode(LED3, OUTPUT);
  pinMode(LED4, OUTPUT);
  pinMode(LED_pulse, OUTPUT);

  pinMode(20, OUTPUT);
  
  pinMode(DET, INPUT);

  cli(); //disables interrupts 
  // setup for interrupts and ISRs
  
  // initializing external pushbutton interrupts

  // attachInterrupt(digitalPinToInterrupt(pin), ISR, mode);
  // attaches an external interrupt to pin in digitalPinToInterrupt, 
  // ISR: the ISR to be called when the interrupt triggers
  // mode: defines when the interrupt should be triggered 
  //
  // possible values for mode: LOW(digital pin is low, CHANGE(when digital pin changes value), 
  // RISING(when digital pin goes from 0 to 1), FALLING(when digital pin goes from 1 to 0)
  attachInterrupt(digitalPinToInterrupt(SW2), SW2_check_state, FALLING);
  attachInterrupt(digitalPinToInterrupt(SW1), SW1_check_state, FALLING);
  
  // initializing timer interrupt
  
  // Clear TPM0_SC(Status and Control) register 
  FTM0_SC = 0;
  
  // Reset the TPM0_CNT counter 
  // TPM0_CNT contains the current counter value of the timer
  FTM0_CNT = timer_start;
  
  // Set overflow value (modulo) (p.574 of FRM)
  // sets the value that the timer will overflow at, max value is 0xFFFF(65535) since 16 bit timer
  
  FTM0_MOD = 0xF423; //62499
  
  
  // Set TPM0_SC register (p. 572 of FRM)
  // Bits | Va1ue | Description
  //  8   |    0  | DMA: Disable DMA
  //  7   |    1  | TOF: Clear Timer Overflow Flag
  //  6   |    1  | TOIE: Enable Timer Overflow Interrupt
  //  5   |    0  | CPWMS: TPM in up counting mode
  // 4-3  |   01  | CMOD: Counter incrememnts every TPM clock
  // 2-0  |  111  | PS: Prescale = 128, ranges from 1-128
  FTM0_SC = 0b011001111;

  // sets the priority of the interrupt, lower value means higher priority
  // ranges from 0-192 with spacing between values of 64
  NVIC_SET_PRIORITY(IRQ_FTM0, 64);

  // enable the timer interrupt
  NVIC_ENABLE_IRQ(IRQ_FTM0);

  sei(); //enables all interrupts

}

// isr for SW2
void SW2_check_state(){
  //checks the state that the state machine was in when interrupt triggered
  if(SPEC.isInState(POWER_SAVING)){
    display.clearDisplay();
    SPEC.transitionTo(IDLE_STATE);
    display.fadein();
    
    // sets the Teensy to normal run mode
    SMC_PMCTRL |= (0 << 6);
    
    reset_timer();
  }else if(SPEC.isInState(IDLE_STATE)){
    SPEC.transitionTo(SCANNING);
    display.clearDisplay();
    display.setCursor(0,0);
    display.print("SCANNING");
    display.display();
  }
  
}

// isr for SW1
void SW1_check_state(){
  //checks the state that the state machine was in when interrupt triggered
  if(SPEC.isInState(POWER_SAVING)){
    //if in power_saving, set next state to idle state
    display.clearDisplay();
    SPEC.transitionTo(IDLE_STATE);
    display.fadein();

    // sets the Teensy to normal run mode
    SMC_PMCTRL |= (0 << 6);
    
    //reset interrupt timer value
    reset_timer();
  }else if(SPEC.isInState(IDLE_STATE)){
    SPEC.transitionTo(BL_SEARCHING);
    reset_timer();
    display.clearDisplay();
    display.setCursor(0,0);
    display.print("BL SEARCHING");
    display.display();
  }//this interrupt should only trigger if it is in idle or power saving state, but just in case

}

void ftm0_isr(void) {

  // First, write a 1 to the TOF bit to clear the timer overflow flag
  FTM0_SC |= (1 << 7);

  // increment the counter
  timer_count++;

  
  if(SPEC.isInState(IDLE_STATE)){
    if(timer_count>=180){//timer has reached 15 minutes
      SPEC.transitionTo(POWER_SAVING);
      reset_timer();
      display.fadeout();

      // sets the Teensy to VLPR mode
      SMC_PMCTRL |= (1 << 6);

    }
  }else if(SPEC.isInState(BL_SEARCHING)){
    if(timer_count>=100){ //not sure if this is needed since it might be done by bluetooth state machine
      SPEC.transitionTo(IDLE_STATE);
      reset_timer();
      display.clearDisplay();
      display.setCursor(0,24);
      display.print("Pairing Failed");
      display.display();
      delay(100);
    }
  }
  
}

//loop that runs repeatedly
void loop() {

  SPEC.update(); // updates the current state of the state machine by setting the current state equal to the next state
}

// function for processes that happen in the IDLE state
void idle() { 

  //display.clearDisplay();
  display.setCursor(0,0);

  int sensorValue = analogRead(A0); //reads in analog value from battery, value will be between 0-8191 since teensy has default 13 bits resolution

  Serial.print("analog 0 is: ");
  Serial.println(sensorValue);
  delay(250);
  //delay(10); // let the ADC recover, arbitrary value
  float voltage = sensorValue*(4.2/8191); //4.2 V is mapped to max value since 3-4.2V is useable range, assumeing voltage will be at 3.3 reference voltage, 
  // safe battery threshold is when sensor value >= 6644
  
  /*if(voltage<3.6){
    display.print("Warning:Low Battery");
  }*/
  
  float Battery_life = ((voltage-3)/1.2); //converts voltage value to a percentage of battery life
  display.setCursor(0,8);
  //display.print(Battery_life); 
  //sensorValue = 97;
  display.print(sensorValue); 
  display.print("%"); 
  display.setCursor(0,16);
  display.print("Not Connected");
  display.display(); //display 
  delay(1); //let the display recover

}

//function for processes that happen in the POWER_SAVING state
void Power_saving(){ 
  //waits in the power_saving state until a pushbutton is pressed, otherwise does nothing
  /*display.clearDisplay();
  display.setCursor(0,0);
  display.print("Power saving");
  display.display();
  delay(1);*/

  //display.fadeout();

  
}
//function for processes that happen in the SCANNING state
void scanning(){ 
  
  //disables all interrupts by clearing the global interrupte mask
  // we disable all interrupts when we enter this state so that the scanning process won't be interrupted
  cli(); 

  //turn on LEDs one-by-one, reads analog value from photodiode for each LED and stores values

  //perform error detecting algorithm
  //   if error occurred
  //      print scanning error to OLED
  //      set next state to idle state
  //   else
  //      perform plastic classification algorithm
  //      print plastic class to OLED
  //      if connected to mobile app
  //         set next state to transmitting state 
  //      else
  //         set next state to idle state

  digitalWrite(20, HIGH);
  delay(6);
  digitalWrite(20,LOW);
  SPEC.transitionTo(IDLE_STATE);
  display.clearDisplay();
  display.setCursor(0,24);
  display.print("Error: No det value");
  display.display();
  delay(1);
  reset_timer();
  sei(); //re-enables interrupts
}

//function for processes that happen in the BL_SEARCHING state
void BL_search(){ 
  
}

//function for processes that happen in the TRANSMITTING state
void data_trans(){ 
  
}

//helper function that just resets the value of timer_count
void reset_timer(){
  timer_count=0;
}

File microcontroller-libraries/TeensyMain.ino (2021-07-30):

/*
 * TeensyMain
 * 
 * Chris Massiello
 * Last Update: 3/5/2021
 * 
 * Description: This program controls the functions of a portable, PLA spectrometer by using a finite
 * state machine. This controls when the spectrometer performs a scan, when the spectrometer tries
 * to connect to a mobile app via bluetooth, and when it goes into power saving mode.
 * 
 */

#include <SPI.h>
#include <Wire.h>
#include <Adafruit_GFX.h>
#include <Adafruit_SSD1306.h>
#include <splash.h>

#include "FiniteStateMachine.h"

// creates list of States that are a part of FSM class
State IDLE_STATE = State(idle);
State POWER_SAVING = State(Power_saving);
State SCANNING = State(scanning);
State BL_SEARCHING = State(BL_search);
State BL_PAIRING = State(BL_pairing);
State PROCESSING = State(data_proc);
State TRANSMITTING = State(data_trans);
State OFF = State(turn_off);

FSM SPEC = FSM(IDLE_STATE); //creates finite state machine class

#define SW1 11 // Pin 11 for SW1, aka pushbutton to start bluetooth pairing
#define SW2 12 // Pin 12 for SW2, aka pushbutton to start plastic scan
#define A0 14 // Pin 14 for monitoring battery level

#define SCREEN_WIDTH 128 // OLED display width, in pixels
#define SCREEN_HEIGHT 64 // OLED display height, in pixels

#define OLED_RESET     4 // Reset pin # (or -1 if sharing Arduino reset pin)
#define SCREEN_ADDRESS 0x3D ///< See datasheet for Address; 0x3D for 128x64, 0x3C for 128x32
Adafruit_SSD1306 display(SCREEN_WIDTH, SCREEN_HEIGHT, &Wire, OLED_RESET);

void setup() {
  // put your setup code here, to run once:
  // Pins 0 and 1 for connection to bluetooth. 0 is RX1, 1 is TX1.
  // Pin 14 for receiving from detector.
  // Pins 18 and 19 for connection to OLED. Pin 18 is SDA0, Pin 19 is SCL0.
  Serial.begin(9600);

  if(!display.begin(SSD1306_SWITCHCAPVCC, SCREEN_ADDRESS)) {
    Serial.println(F("SSD1306 allocation failed"));
    for(;;); // Don't proceed, loop forever
  }

  pinMode(SW1, INPUT);
  pinMode(SW2, INPUT);

}

void loop() {
  // put your main code here, to run repeatedly:
  
  if(SPEC.isInState(IDLE_STATE)){ //if current state is idle
    if(digitalRead(SW2)){ //if SW2 is high, user wants to take a scan, set next state to be SCANNING
      SPEC.transitionTo(SCANNING); 
    }else if(digitalRead(SW1)){ //if SW1 is high, user wants to bluetooth pair, set next state to be 
      SPEC.transitionTo(BL_SEARCHING);
    }else if(SPEC.timeInCurrentState()>=90000){ //if it has been in the idle state for more than 15 minutes (900000 ms), go to power saving state
      // transition to VLPR
      SPEC.transitionTo(POWER_SAVING);
    }else{
      SPEC.selfTransitionTo(IDLE_STATE); // stays in idle state if no button is pressed and it hasn't been 15 minutes in idle state
    }
    
  }else if(SPEC.isInState(POWER_SAVING)){ //if in power saving state
    if(SPEC.timeInCurrentState()>=180000){ //if it has been in the power saving state for more than 30 minutes (1800000 ms), go to power saving state
      SPEC.transitionTo(OFF); // turn off
    }else if(digitalRead(SW2)||digitalRead(SW1)){  // if user presses a button, go back to idle
      SPEC.transitionTo(IDLE_STATE);
    }else{
      SPEC.selfTransitionTo(POWER_SAVING);  // if nothing happens, stay in POWER_SAVING
    }
  
  }else if(SPEC.isInState(SCANNING)){
    
  }else if(SPEC.isInState(BL_SEARCHING)){
    
  }else if(SPEC.isInState(BL_PAIRING)){
    
  }else if(SPEC.isInState(PROCESSING)){
    
  }else if(SPEC.isInState(TRANSMITTING)){
    
  }
  SPEC.update(); // causes state machine to update and go to next state
}


void idle() { //function for processes that happen in the IDLE state
  int sensorValue = analogRead(A0); //reads in analog value from battery, value will be between 0-8191 since teensy has default 13 bits resolution
  // might need to make sensorValue a global variable
  float voltage = sensorValue*(3.7/8191); //3.7 V is mapped to max value since 3-3.7V is useable range, assumeing voltage will be at 3.3 reference voltage, 
  // safe battery threshold is when sensor value >= 6644
  float Battery_life = ((voltage-3)/0.7)*100; //converts voltage value to a percentage of battery life
  display.print(Battery_life); 

  
}
void Power_saving(){ //function for processes that happen in the POWER_SAVING state
  
}

void scanning(){ //function for processes that happen in the SCANNING state
  
}

void BL_search(){ //function for processes that happen in the BL_SEARCHING state
  
}

void BL_pairing(){ //function for processes that happen in the BL_PAIRING state
  
}

void data_proc(){ //function for processes that happen in the PROCESSING state
  
}

void data_trans(){ //function for processes that happen in the TRANSMITTING state
  
}
void turn_off(){

}

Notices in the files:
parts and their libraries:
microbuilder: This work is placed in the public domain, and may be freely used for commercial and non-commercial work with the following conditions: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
